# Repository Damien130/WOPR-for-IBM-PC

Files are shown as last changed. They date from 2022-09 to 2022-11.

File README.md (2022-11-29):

# WOPR-for-IBM-PC
A WOPR control panel for the IBM PC (/XT)'s full height 5.25 inch drive bay

WOPR, acronym for War Operation Plan Response, is a supercomputer in the 80s movie War Games. Other than its inherent purpose of planning to start a global thermonuclear war and constant drive to play a good game of chess, it also has lots, lots of LEDs flashing all around it. Although the 5150/60 Personal Computers bears little resemblance to WOPR itself, the WOPR’s control panel will fit right into the IBM beige box design of the 80s. 

The purpose of this design project is to replicate part of WOPR’s main control panel to fit inside a full-height 5.25-inch drive bay of the IBM 5160 PC/XT. The panel will consist of 16 LEDs, a push button to generate a reset signal to the P8284A clock generator, a “Turbo Switch” to select between 4.77 MHz and 7.2 MHz clock frequency for the PC-SPRINT board and on/off switch for the entire LED panel.

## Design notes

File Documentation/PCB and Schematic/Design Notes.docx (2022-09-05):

# WOPR for IBM 5150/60

Schematic and PCB details

# Circuit Schematic:

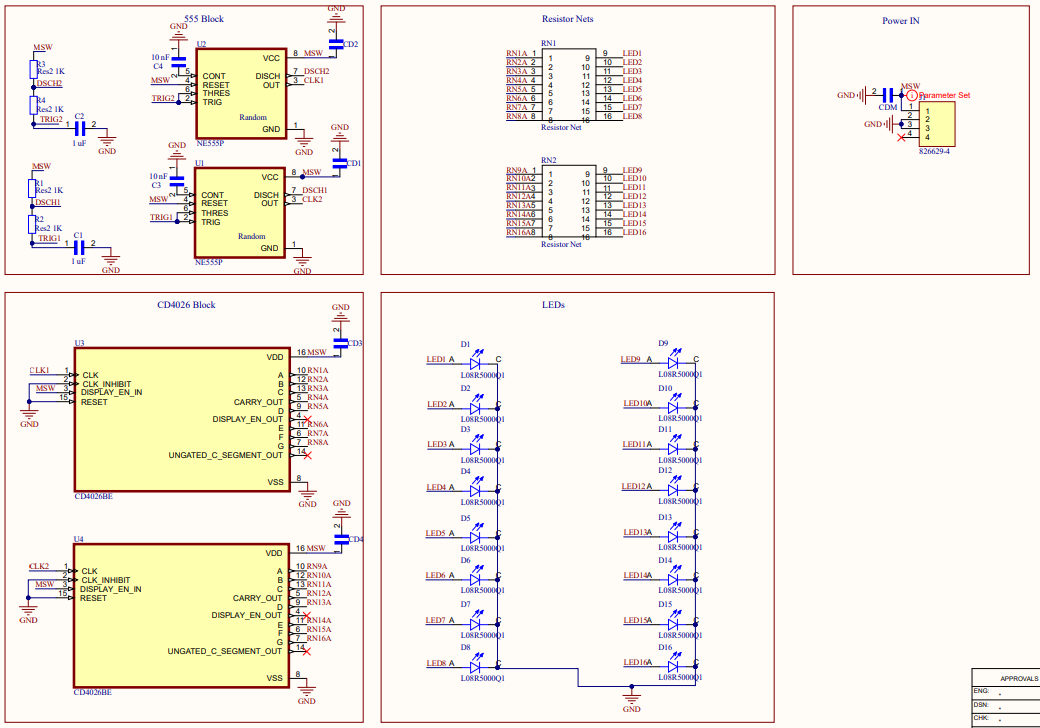
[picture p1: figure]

The schematic again uses hierarchical design although all the components fit on a single page. Different modules (555, CD4026 etc.) occupies individual blocks with interconnections done through net names to avoid debugging confusion.

The two 555 timers will provide two different clock signals to the two CD4026s, which will generate two different counting speed. The 555 resistor values show in the schematic is a placeholder, actual resistor values will be changed. The CD4026s will then directly drive the 16 LEDs (8 each) through two DIP resistor nets to create a random blinker effect. The resistor value is 500 ohms, this is to limit the voltage and current going through the LEDs to 20mA @ 2Volts (output voltage from the CD4026s will be at approximately 11-12 volts).

The board power will be provided by the IBM 5160’s 12V rail. A 4-pin header is included for this purpose. A cable will be constructed with 4pos Molex-D plug on one end and Dupont headers on the other. The master switch will be in series with the 12Volts line and mounted externally on the enclosure’s front panel to turn the unit on/off.

LEDs are orange LEDs rated for 200 millicandelas. It’ll be neither too bright nor too dim.

# PCB Design

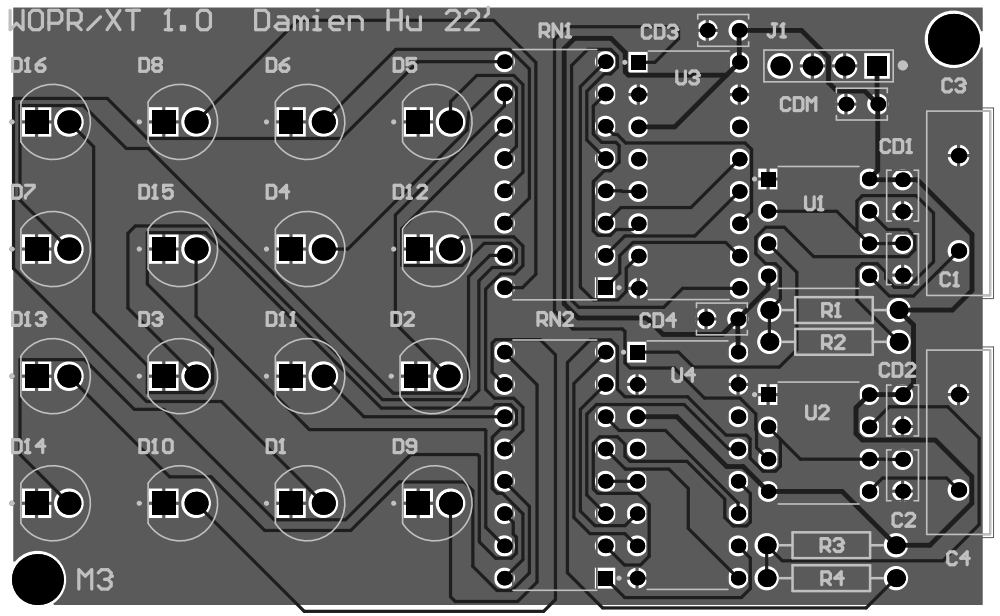
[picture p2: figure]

The PCB size is 78.9mm x 50.1mm (3.106 x 1.972 inches). The PCB can be divided approximately down the centerline into two parts – the LED quadrant and logic quadrant.

The LEDs are separated exact 1 cm from each other. Different pad shapes are included to distinguish positive from negative as the LEDs will be mounted on the bottom side of the PCB.

Both the CD4026 and resistor nets are packaged in DIP-16 to minimize clutter. All the ICs are locally decoupled with a net decoupler near the input of J1.

The grey area on the PCB is the GND plane. It occupies the entire back side of the board with all traces running on the top layer. Main power traces are thickened to 15 mils, should be more than sufficient for the rated power consumption of the completed PCB.

Two M3 mounting holes are provided if the 3D printed enclosure design passes QC and becomes ready for a laser cut acrylic version.

# Design Rule Check

*Rules are only checked against JLCPCB’s manufacturing constraints.

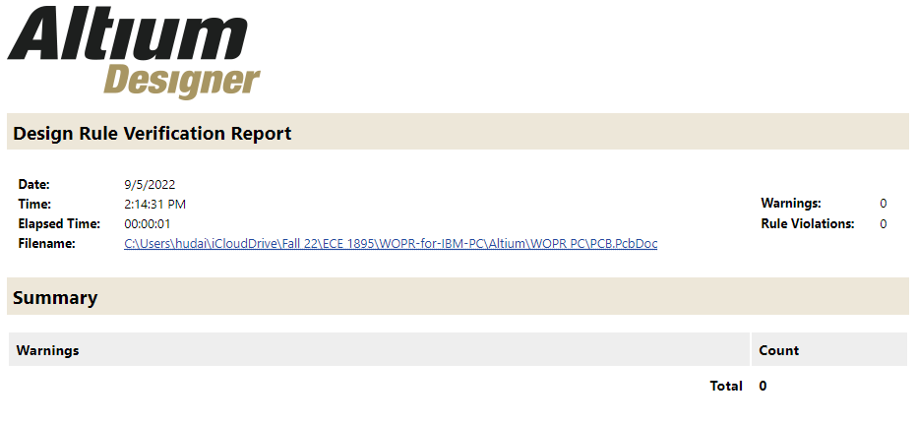
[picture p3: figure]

No rule violations are found.

# Altium generated Bill of Materials

Comment | Description | Designator | Footprint | LibRef | Quantity
FG18X7R1E105KRT00 | COMMERCIAL GRADE, HALOGEN FREE DIPPED RADIAL / BULK | C1, C2 | CAPRB250W50L400T250H550 | FG18X7R1E105KRT00 | 2
CK45-E3DD103ZYGNA | Cap Ceramic Single 0.01uF 2000V E -20% to 80% (14.5 X 5mm) Radial Disc 7.5mm 105Â°C Bag | C3, C4 | CAPRB750W60L1450T500H1850 | CK45-E3DD103ZYGNA | 2
FG18X7R1H473KNT06 | COMMERCIAL GRADE, HALOGEN FREE DIPPED RADIAL / AMMO PACK | CD1, CD2, CD3, CD4, CDM | CAPRB250W50L400T250H550 | FG18X7R1H473KNT06 | 5
L08R5000Q1 | LED, Orange, Through Hole, T-1 3/4 (5mm), 30 mA, 2.1 V, 635 nm | D1, D2, D3, D4, D5, D6, D7, D8, D9, D10, D11, D12, D13, D14, D15, D16 | LEDRD254W57D500H1070 | L08R5000Q1 | 16
826629-4 | Conn Unshrouded Header HDR 4 POS 2.54mm Solder ST Thru-Hole Automotive Carton | J1 | TE_826629-4 | 826629-4 | 1
Res2 | Resistor | R1, R2, R3, R4 | AXIAL-0.4 | Res2 | 4
Resistor Net | Resistor net, 510Ohm, 2%, 2.25W. 16Pin DIP Thru Hole. 8 Resistors. | RN1, RN2 | DIP794W45P254L1969H508Q16 | 4116R-1-511LF | 2
NE555P | | U1, U2 | DIP794W45P254L959H508Q8 | NE555P | 2
CD4026BE | CMOS Decade Counter/Divider with Decoded 7-Segment Display Outputs and Display Enable 16-PDIP -55 to 125 | U3, U4 | DIP794W45P254L1969H508Q16 | CD4026BE | 2

Note: As there are no available footprints for the DIP-16 resistor net, I created a custom symbol and coupled it with a generic DIP-16 footprint. The library file can be found in the Altium folder of the repository.

GitHub: https://github.com/Damien130/WOPR-for-IBM-PC.git

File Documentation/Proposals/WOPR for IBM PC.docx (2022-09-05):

# WOPR for IBM 5150/60

Project Proposal

# Why WOPR?

WOPR, acronym for War Operation Plan Response, is a supercomputer in the 80s movie War Games. Other than its inherent purpose of planning to start a global thermonuclear war and constant drive to play a good game of chess, it also has lots, lots of LEDs flashing all around it. Although the 5150/60 Personal Computers bears little resemblance to WOPR itself, the WOPR’s control panel will fit right into the IBM beige box design of the 80s.

# What will it look like?

The purpose of this design project is to replicate part of WOPR’s main control panel to fit inside a full-height 5.25-inch drive bay of the IBM 5160 PC/XT. The panel will consist of 16 LEDs, a push button to generate a reset signal to the P8284A clock generator, a “Turbo Switch” to select between 4.77 MHz and 7.2 MHz clock frequency for the NEC V20 Processor (CMOS/improved version of Intel 8088 with 80186/286 instruction support) and on/off switch for the entire LED panel.

# Original Designs

The design takes inspiration from my previous ignition board design for the Pitt SOAR rocket team, whose clock section was based on a 7400-series digital clock on hackster.io - 7400 Series Logic Clock - Hackster.io (https://www.hackster.io/harit-shah/7400-series-logic-clock-9c9b9f). The 7400-clock on hackster.io used a Maxim Integrated DS3231M I2C real time clock to provide the 1Hz square wave, but I substituted it with a 555-timer running at 1Hz for SOAR.

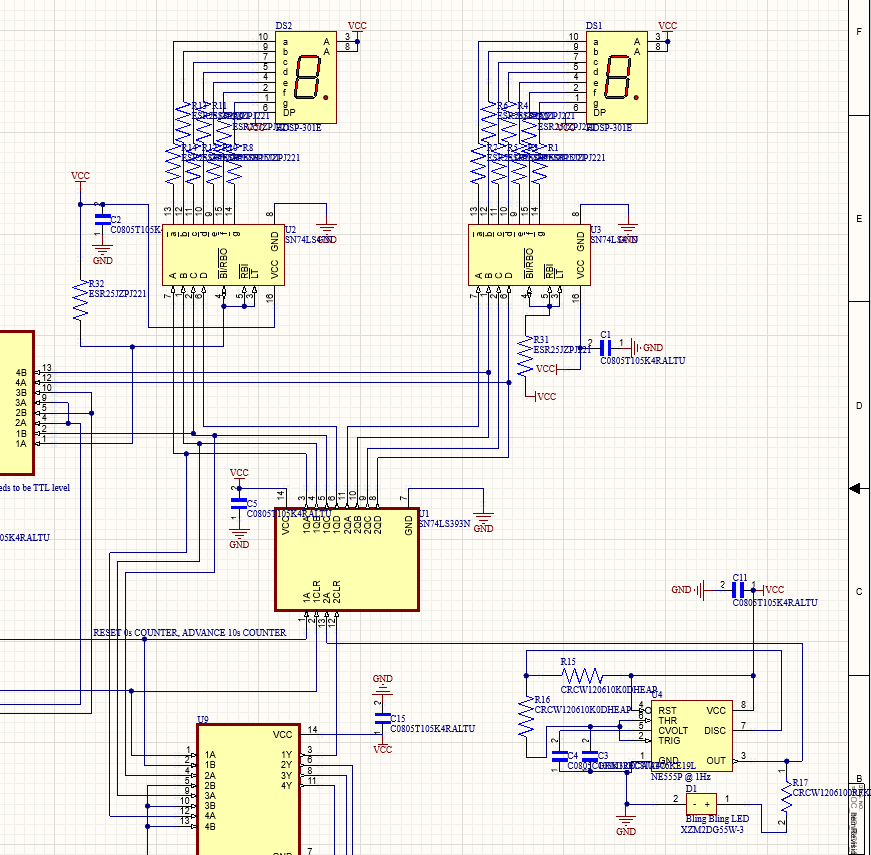
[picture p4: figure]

# Modifications + Improvements

The new design done away with the 7400 series logic and combined the entire counting + 7Seg driver circuitry with the CD4026 decade counter + display driver chip. One significant issue with using CMOS circuitry is its ability to source current for the LEDs (20 mA).

Thanks to the IBM PC/XT’s built-in 12-volt power supply (which can supply up to 2.4 amps due to the massive motor required to spin up the WD-25 hard disk drive’s 4 platters to 3600 RPM), the entire WOPR board will be supplied with 12V. Based on the CD4026’s datasheet, the CD4026 should be able to supply at least 20 mA @ 12V in WOPR’s common cathode LED configuration:

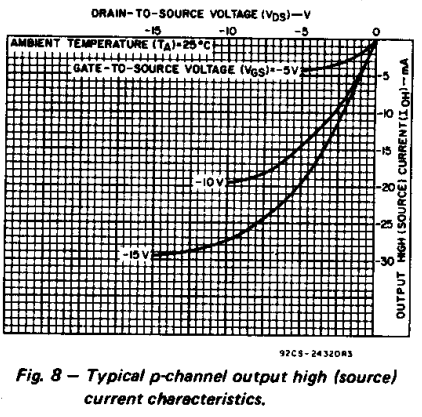
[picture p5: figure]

Two 500-ohm resistor nets in DIP-16 package were used to control the output current to the LEDs. As the CD4026 also comes in a DIP-16 package, it allows a cleaner and more compact PCB layout.

The PCB will fit behind a custom designed 3D-printed (or laser cut acrylic if the 3d printed model fits properly) front panel with WOPR – War Operation Plan Response printed along with IBM’s logo on the top left. 3 holes on the right side will be for the reset button, turbo switch and WOPR master switch.

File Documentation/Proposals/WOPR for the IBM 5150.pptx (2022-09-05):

## WOPR for the IBM 5150/60

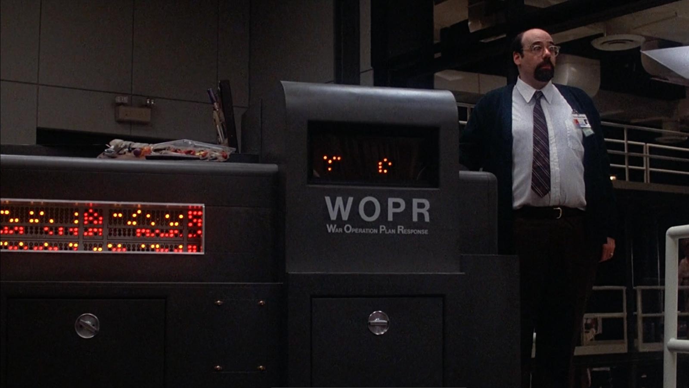
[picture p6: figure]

Or only the LEDs, really.
*Apple ][ not included

## What is WOPR?

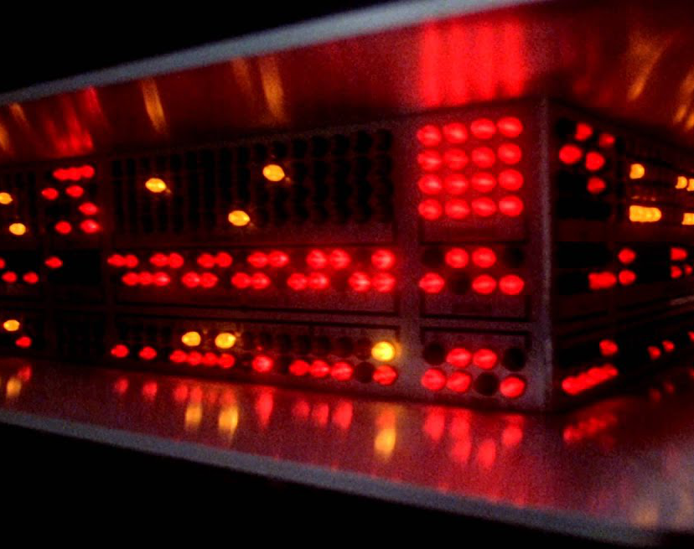
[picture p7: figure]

- WOPR, or War Operation Plan Response, is a supercomputer in the 1983 movie War Games. Although not having that many registers, WOPR has loads of LEDs all around it to make it look “super”. The computer controlling the LEDs were an Apple //e.
- There’s a possible Soviet equivalent designed by the late General Secretary Gorbachev called the ЪЇGMДҠ.
- Failed attempt at regression Machine Learning
- The IBM PC happens to be from the same era.

## Where to put the WOPR (https://www.redditmedia.com/r/computers/comments/wy9q4e/the_soothing_sound_of_the_wd25_hdd/?amp;ref=share)?

- The IBM 5150/60, or the IBM PC(/XT), are the first computers to come with 5.25-inch full height drive bays. They originally contains 2 Tandon 360k DD floppy drives, and later models like my PC/XT contains 1 or 2 360k half-heigh floppy drives and 1 Western Digital WD-25 20 Million Characters Fixed disk drive.
- The IBM fixed disk controller recently gave up and started to throw ECC errors. Unable to source the SRAMs used as its disk buffers, it’s time to replace the drive! WOPR would fit right in, right?

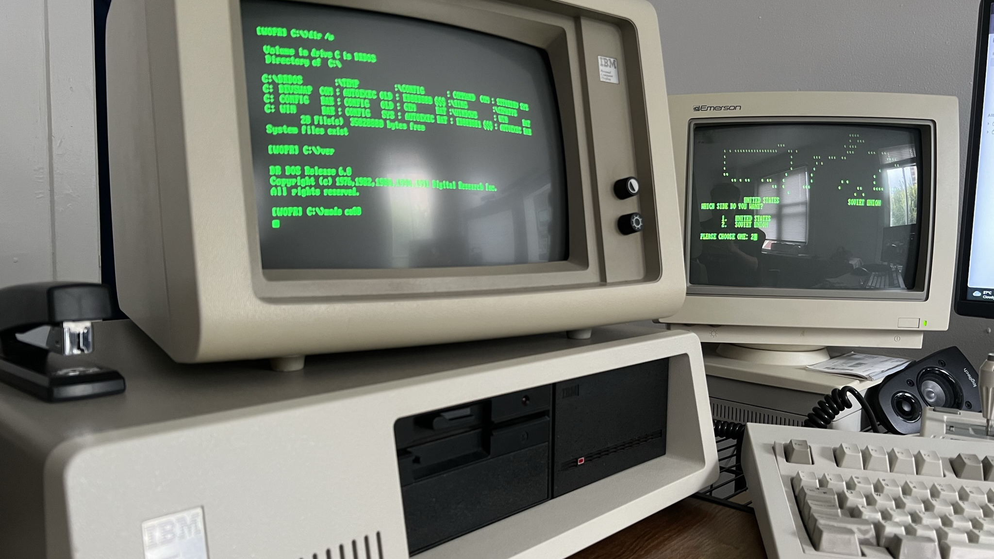
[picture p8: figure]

## Original Design

- The design took inspiration from my previous ignition board design for the Pitt SOAR rocket team, whose count-down clock section was in turn based on a 7400-series digital clock on hackster.io - 7400 Series Logic Clock - Hackster.io (https://www.hackster.io/harit-shah/7400-series-logic-clock-9c9b9f). The 7400-clock on hackster.io used a Maxim Integrated DS3231M I2C real time clock to provide the 1Hz square wave, but I substituted it with a 555-timer running at 1Hz for SOAR.

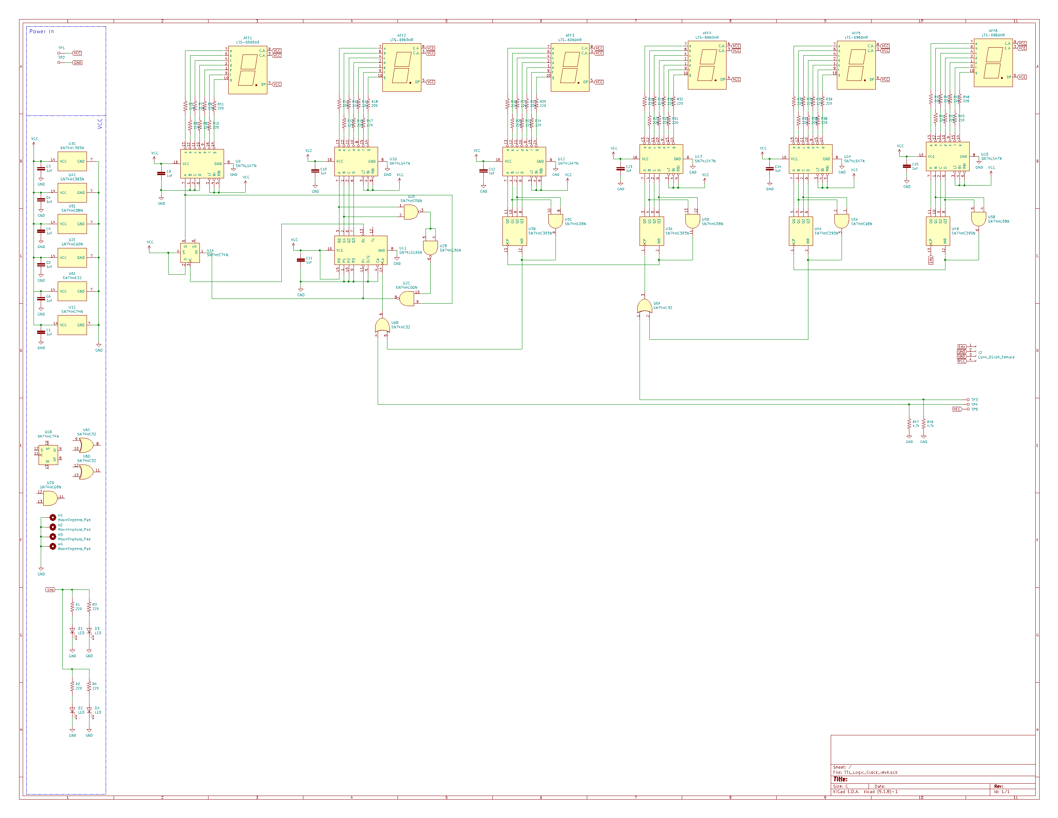
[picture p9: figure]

## Modification + Improvements

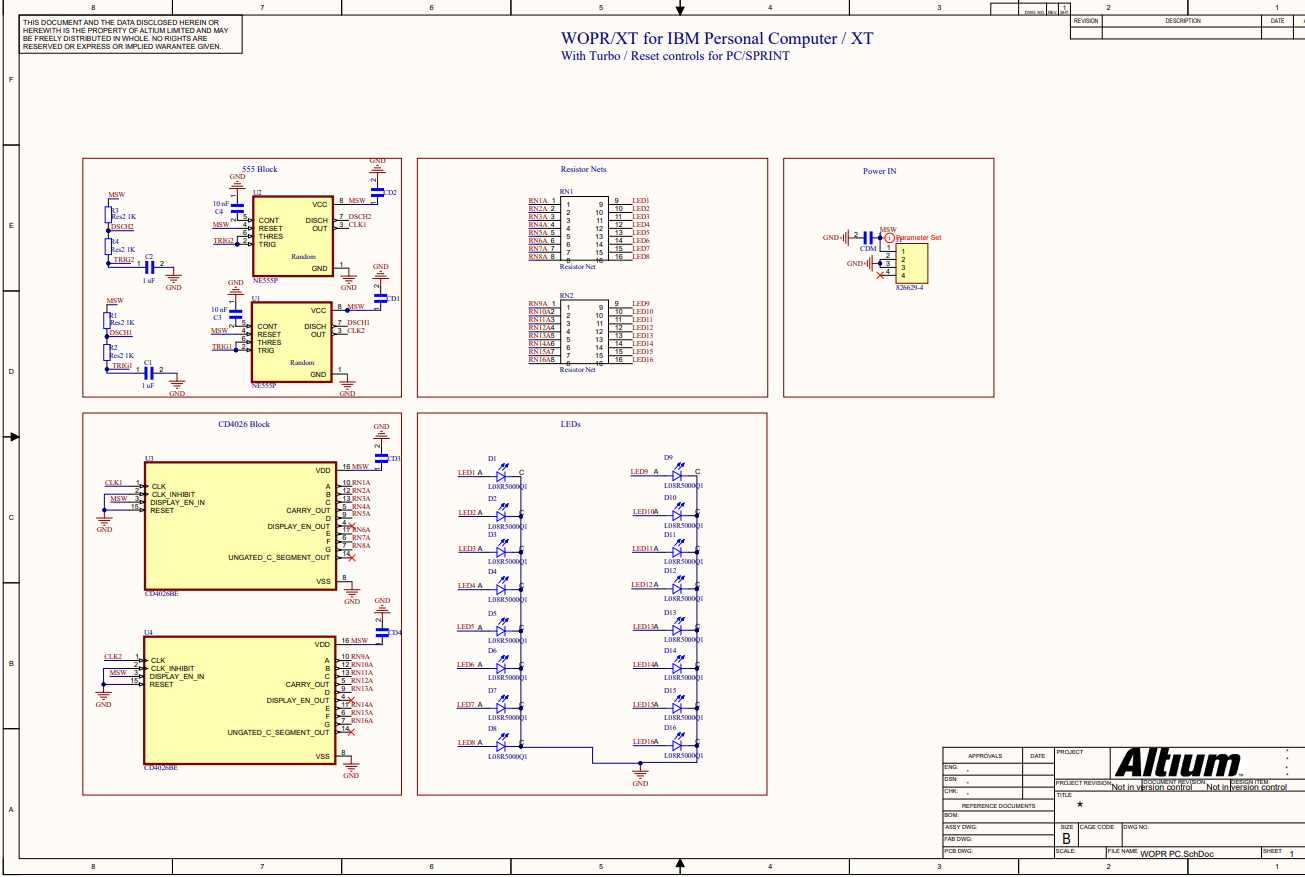
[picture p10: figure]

- The new design done away with the 7400 series logic and combined the entire counting + 7Seg driver circuitry with the CD4026 decade counter + display driver chip. The CD4026 will then directly drive 16 LEDs instead of 2 7-seg displays to create the illusion of “randomly blinking LEDs thinking how to win a good game of chess.”
- The entire board will be powered by the IBM PC’s 12V power supply with a MOLEX 4 pos D-Connector –> 4 pin female header cable, which should be sufficient for the CD4026 CMOS chip to output the 20mA current needed for the LEDs.

## Enclosure Design

- 3D-printed 5.25-inch bay mount. The three holes on the right side of the front panel are for the RESET button, “TURBO” switch (both features of the home brew PC/SPRINT clock board, boosting the 8088 from 4.77MHz to 7.2MHz) and the WOPR’s master power button in case it tries to launch nukes.

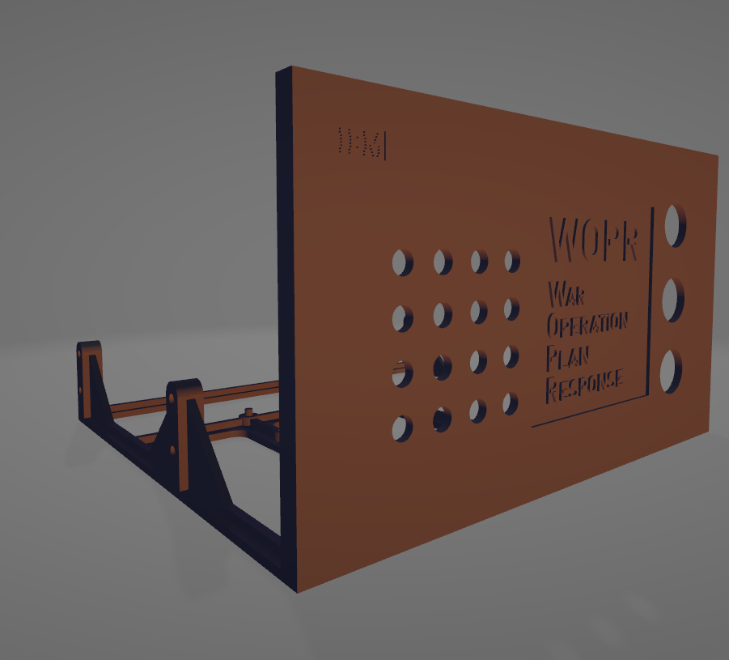
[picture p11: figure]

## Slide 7

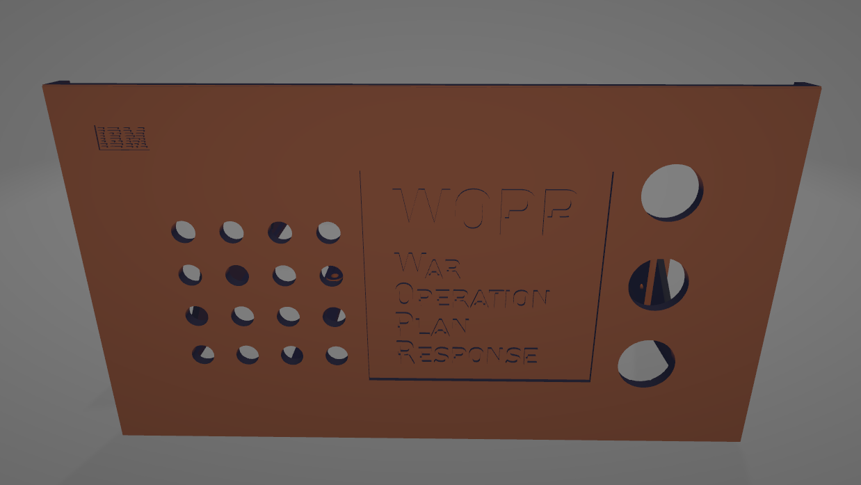
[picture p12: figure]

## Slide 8

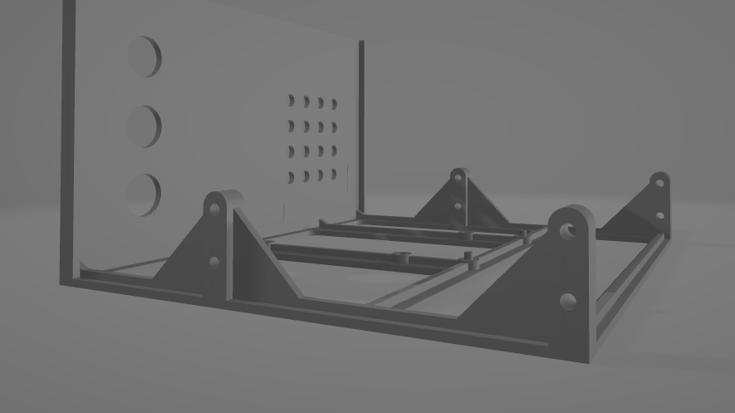
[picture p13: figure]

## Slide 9

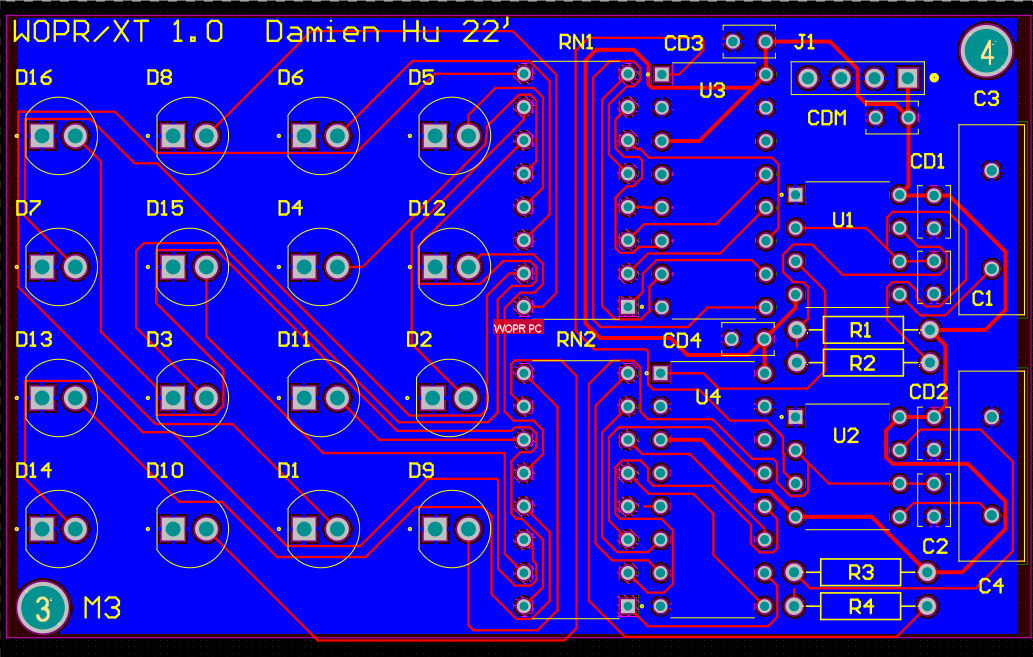
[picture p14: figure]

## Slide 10

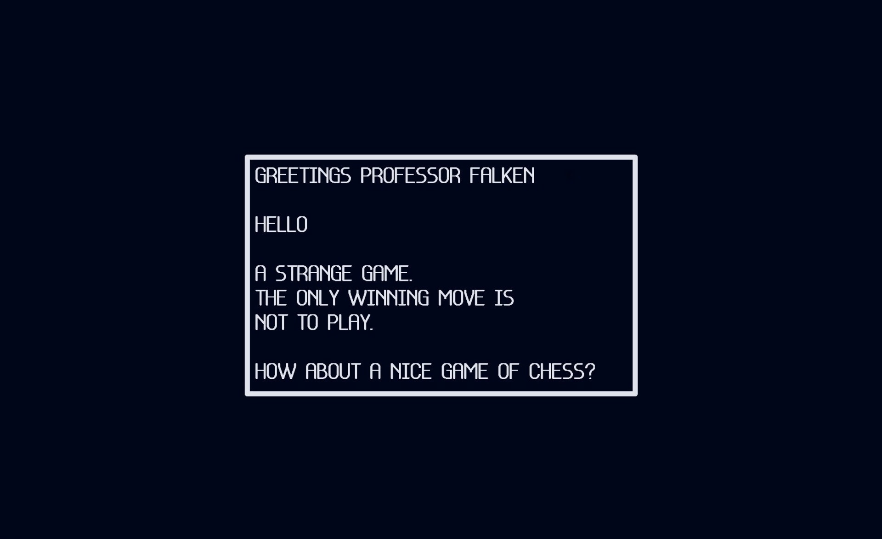
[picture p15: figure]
2193025 - safe, artist:mkogwheel edits, edit, applejack, earth pony, pony, applejack's sign, dialogue, female, mare, meme, solo, text, the game, when you see it - Derpibooru

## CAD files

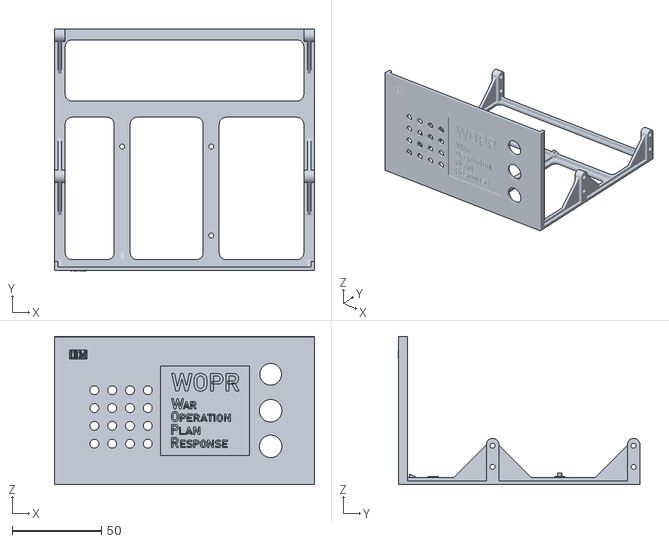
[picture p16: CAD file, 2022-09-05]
Enclosure Models/WOPR Final.stl
146.0 x 135.8 x 83.3

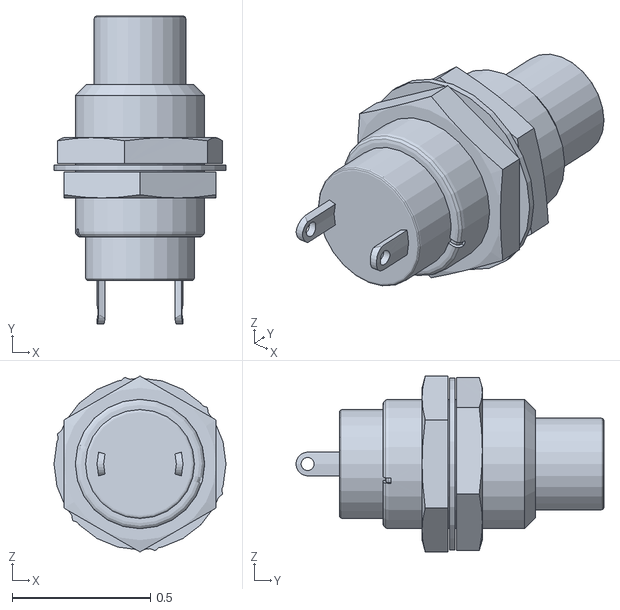
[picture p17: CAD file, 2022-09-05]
Enclosure Models/Push Button.stl
0.622 x 1.11 x 0.636

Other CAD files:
Enclosure Models/Mounting model.stl

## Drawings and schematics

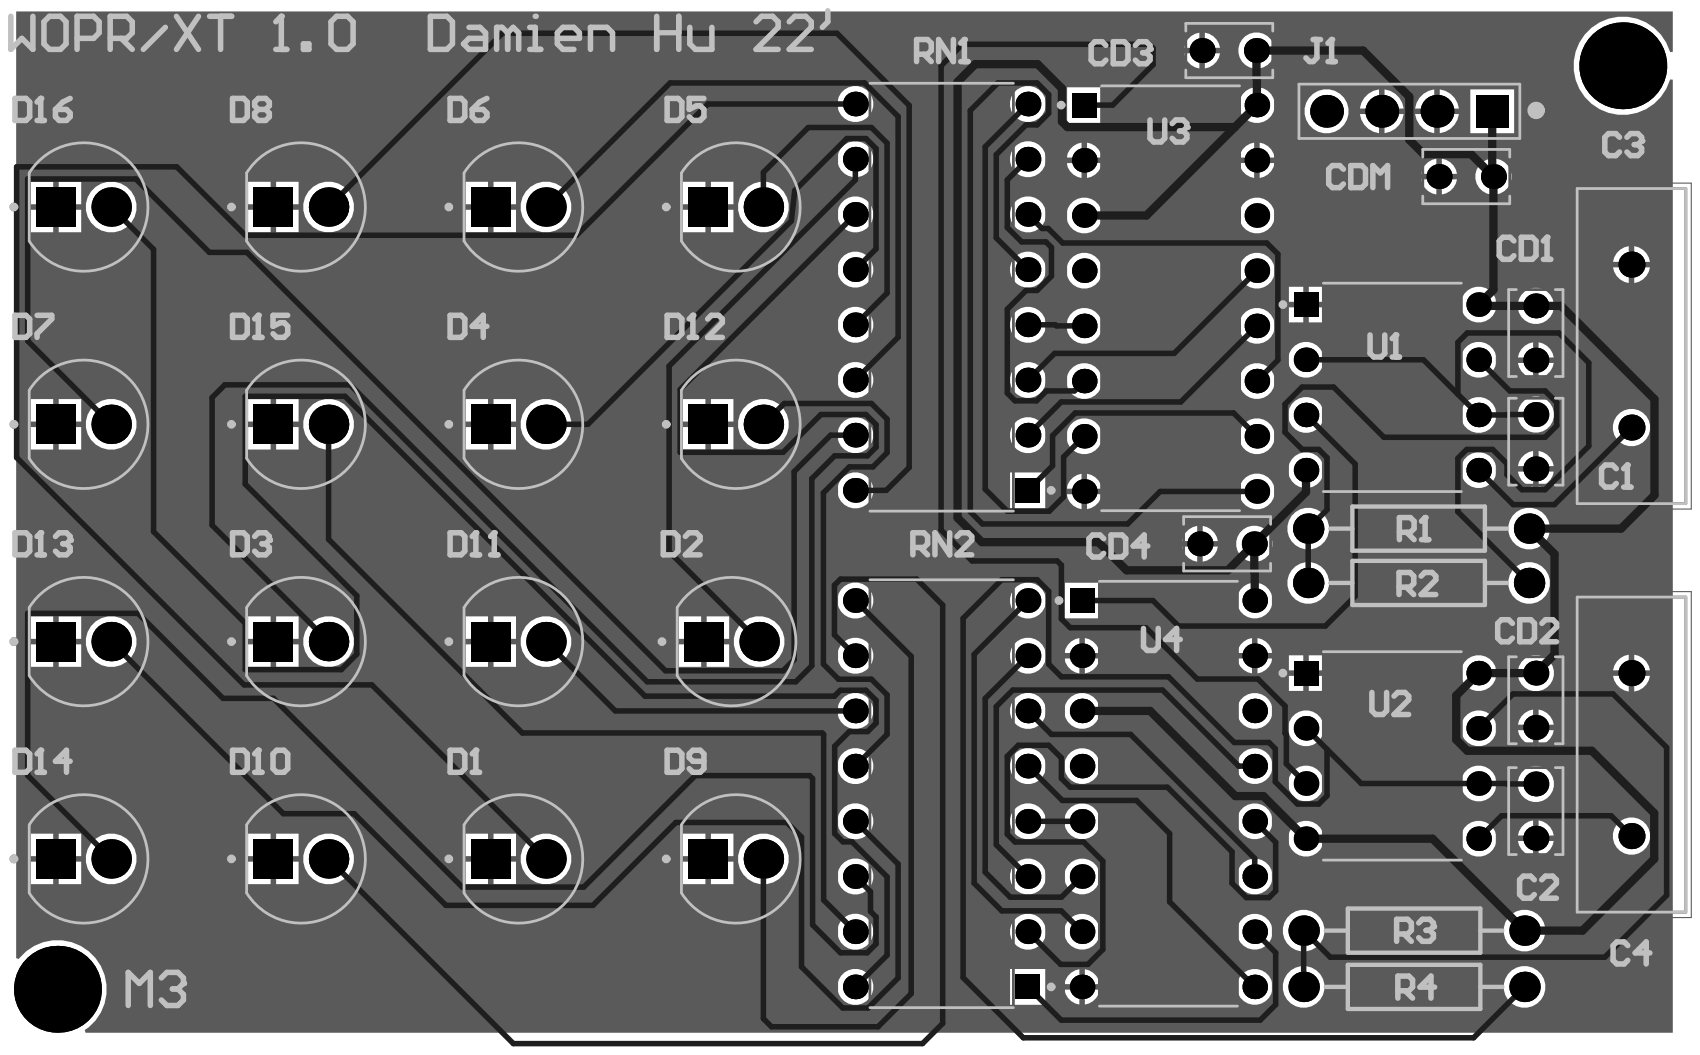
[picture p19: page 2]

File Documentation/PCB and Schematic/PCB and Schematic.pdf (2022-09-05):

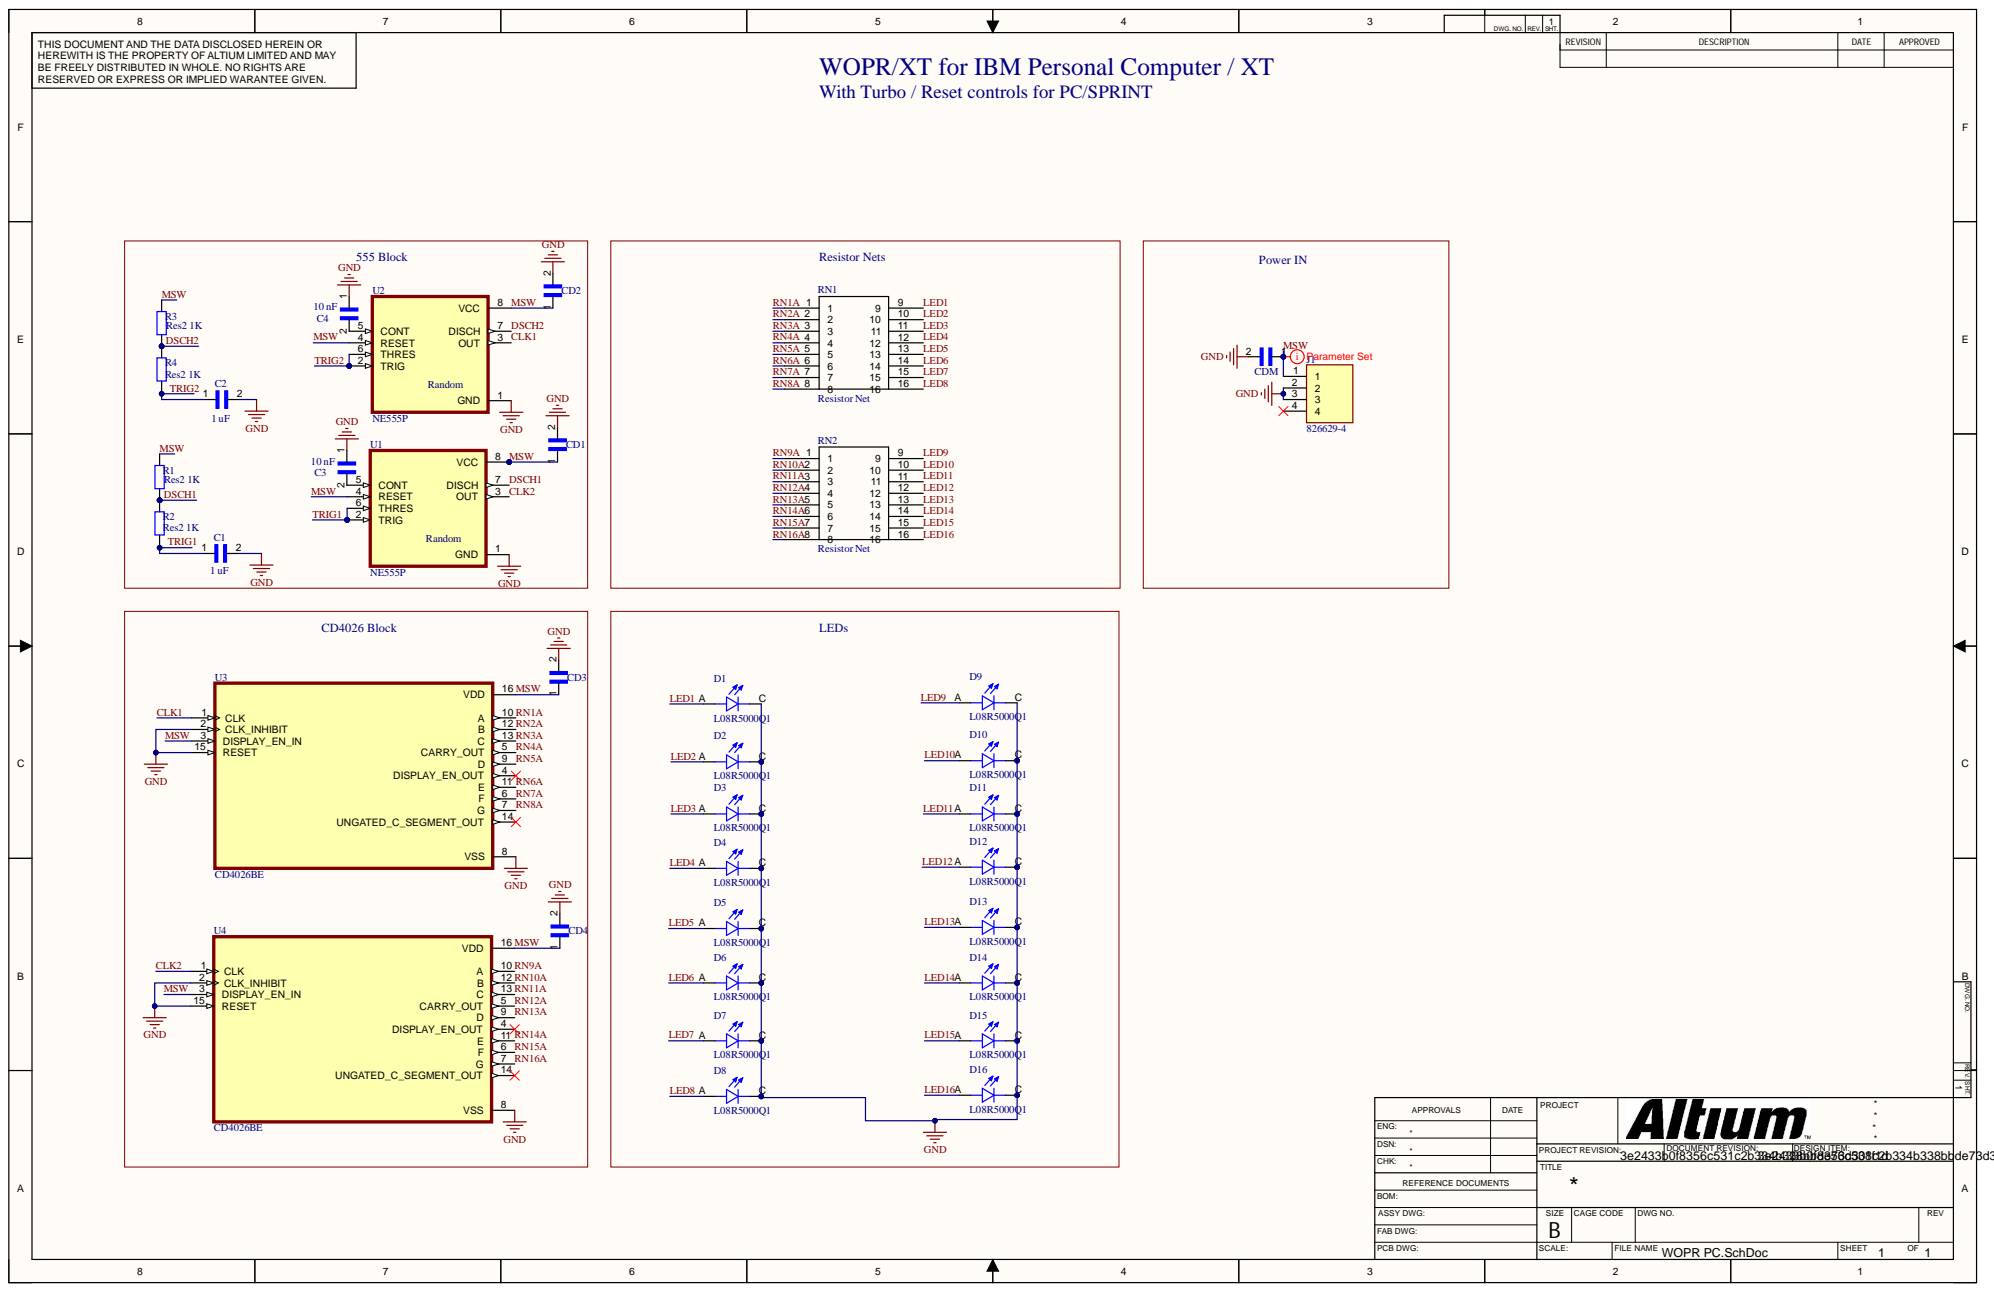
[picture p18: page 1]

DWG. NO | . REV | 1 . SHT | .

TH IS D O C UMEN T AN D THE D ATA D ISCLOSED HEREI N O R HEREWITH IS THE PR OPERTY OF ALTI UM LIMITED AN D MAY BE FREEL Y D ISTR IBUTED I N WH OLE. N O R I G HTS AR E RESERVED O R EXPRESS O R IMPLIED WARANTEE G IVEN . | | RE VISION | DE SCRIPTION | DATE | A P PROV E D

WOPR/XT for IBM Personal Computer / XT With Turbo / Reset controls for PC/SPRINT

REV. SHT. DWG. NO.

PROJEC T REVISION : 3e2433b0f8356c531c2b334b338bbde73d 3e2433b0f8356c531c 308f12b334b338bbde73d d | DOC U MEN T REVISION : | DESIGN I TEM :
